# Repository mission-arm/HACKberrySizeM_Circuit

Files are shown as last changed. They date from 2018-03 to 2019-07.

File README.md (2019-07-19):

# HACKberrySizeM_Circuit

This repository contains circuit design of middle sized [HACKberry](https://github.com/mission-arm/HACKberry).

## Licenses

The electrical circuit design of [HACKberry](https://github.com/mission-arm/HACKberry) by [Exiii](info@exiii.jp) is licensed under [Creative Commons License BY-NC-SA 4.0 International](https://creativecommons.org/licenses/by-nc-sa/4.0/).
( Please refer to chapter 3.1 in [Original HACKberry Lincense](https://github.com/mission-arm/HACKberry) for detail. )

And This electrical circuit design of  middle sized HACKberry ) is a derivative of HACKberry and is licensed under [Creative Commons License BY-NC-SA 4.0 International](https://creativecommons.org/licenses/by-nc-sa/4.0/) by MissionARMJapan.

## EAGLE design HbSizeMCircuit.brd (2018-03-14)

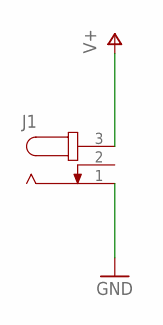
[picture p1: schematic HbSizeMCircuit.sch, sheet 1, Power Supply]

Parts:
J1: JACK-PLUG1; SPC4078

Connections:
GND: J1.1; also elsewhere on the board
V+: J1.3; also elsewhere on the board

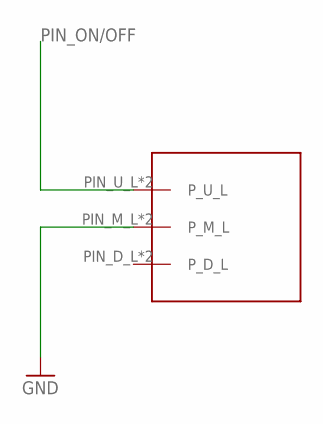
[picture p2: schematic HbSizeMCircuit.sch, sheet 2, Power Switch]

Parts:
U$2: IS-1250_POWERSWITCH

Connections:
GND: U$2.PIN_M_L (P_M_L), U$2.PIN_M_R (P_M_L); also elsewhere on the board
PIN_ON/OFF: U$2.PIN_U_L (P_U_L), U$2.PIN_U_R (P_U_L); also elsewhere on the board

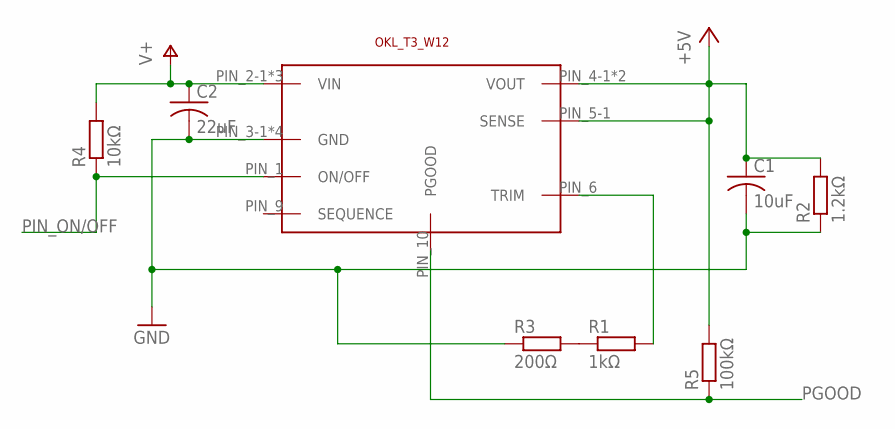
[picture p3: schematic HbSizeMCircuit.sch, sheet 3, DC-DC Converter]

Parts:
C1: 10uF; C1206
C2: 22uF; C1206
R1: 1kΩ; M1206
R2: 1.2kΩ; M1206
R3: 200Ω; M1206
R4: 10kΩ; R1206
R5: 100kΩ; M1206
U$8: OKL_T3_W12

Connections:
+5V: C1.1, R2.2, R5.2, U$8.PIN_4-1 (VOUT), U$8.PIN_4-2 (VOUT), U$8.PIN_5-1 (SENSE); also elsewhere on the board
GND: C1.2, C2.2, R2.1, R3.1, U$8.PIN_3-1 (GND), U$8.PIN_3-2 (GND), U$8.PIN_3-3 (GND), U$8.PIN_7 (GND); also elsewhere on the board
unnamed: R1.2, U$8.PIN_6 (TRIM)
unnamed: R1.1, R3.2
PGOOD: R5.1, U$8.PIN_10 (PGOOD); also elsewhere on the board
PIN_ON/OFF: R4.1, U$8.PIN_1 (ON/OFF); also elsewhere on the board
V+: C2.1, R4.2, U$8.PIN_2-1 (VIN), U$8.PIN_2-2 (VIN), U$8.PIN_2-3 (VIN); also elsewhere on the board

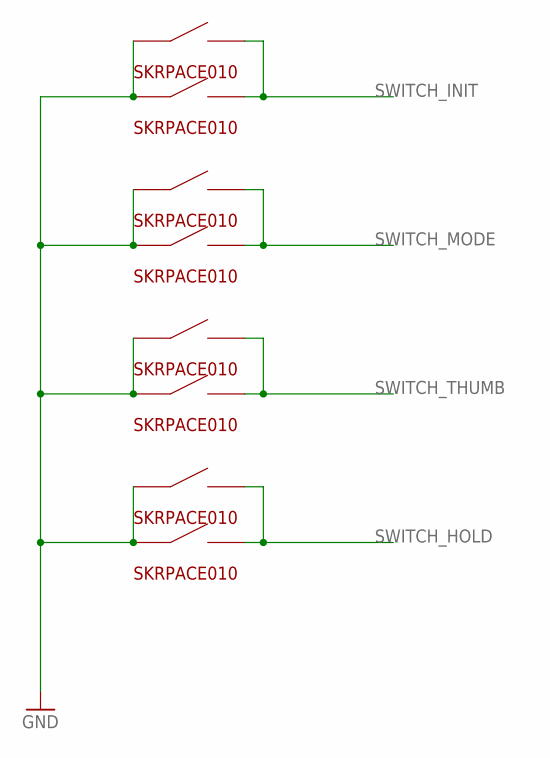
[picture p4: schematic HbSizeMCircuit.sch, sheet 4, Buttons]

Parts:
U$1, U$3, U$4, U$5, U$12, U$13, U$14, U$15: SKRPACE010

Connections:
GND: U$1.PINA_LEFT (A_LEFT), U$1.PINA_RIGHT (A_LEFT), U$3.PINA_LEFT (A_LEFT), U$3.PINA_RIGHT (A_LEFT), U$4.PINA_LEFT (A_LEFT), U$4.PINA_RIGHT (A_LEFT), U$5.PINA_LEFT (A_LEFT), U$5.PINA_RIGHT (A_LEFT), U$12.PINA_LEFT (A_LEFT), U$12.PINA_RIGHT (A_LEFT), U$13.PINA_LEFT (A_LEFT), U$13.PINA_RIGHT (A_LEFT), U$14.PINA_LEFT (A_LEFT), U$14.PINA_RIGHT (A_LEFT), U$15.PINA_LEFT (A_LEFT), U$15.PINA_RIGHT (A_LEFT); also elsewhere on the board
SWITCH_HOLD: U$12.PINB_LEFT (B_LEFT), U$12.PINB_RIGHT (B_LEFT), U$15.PINB_LEFT (B_LEFT), U$15.PINB_RIGHT (B_LEFT); also elsewhere on the board
SWITCH_INIT: U$1.PINB_LEFT (B_LEFT), U$1.PINB_RIGHT (B_LEFT), U$5.PINB_LEFT (B_LEFT), U$5.PINB_RIGHT (B_LEFT); also elsewhere on the board
SWITCH_MODE: U$3.PINB_LEFT (B_LEFT), U$3.PINB_RIGHT (B_LEFT), U$13.PINB_LEFT (B_LEFT), U$13.PINB_RIGHT (B_LEFT); also elsewhere on the board
SWITCH_THUMB: U$4.PINB_LEFT (B_LEFT), U$4.PINB_RIGHT (B_LEFT), U$14.PINB_LEFT (B_LEFT), U$14.PINB_RIGHT (B_LEFT); also elsewhere on the board

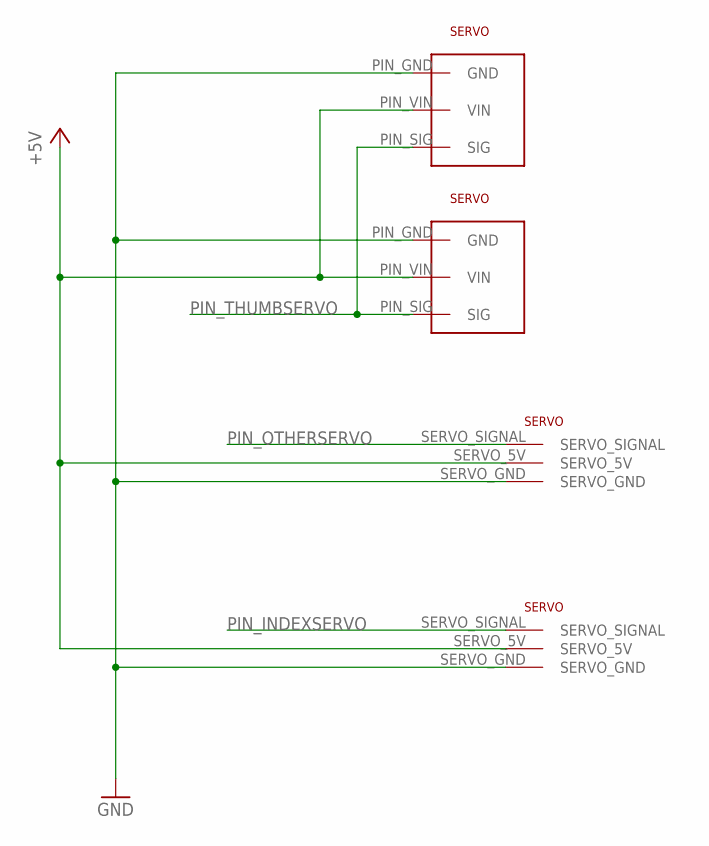
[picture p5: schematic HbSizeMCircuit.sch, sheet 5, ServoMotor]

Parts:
U$7, U$11: NN_SERVO
U$9, U$16: 53398-0371

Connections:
+5V: U$7.SERVO_5V, U$9.PIN_VIN (VIN), U$11.SERVO_5V, U$16.PIN_VIN (VIN); also elsewhere on the board
GND: U$7.SERVO_GND, U$9.PIN_GND (GND), U$11.SERVO_GND, U$16.PIN_GND (GND); also elsewhere on the board
PIN_INDEXSERVO: U$11.SERVO_SIGNAL; also elsewhere on the board
PIN_OTHERSERVO: U$7.SERVO_SIGNAL; also elsewhere on the board
PIN_THUMBSERVO: U$9.PIN_SIG (SIG), U$16.PIN_SIG (SIG); also elsewhere on the board

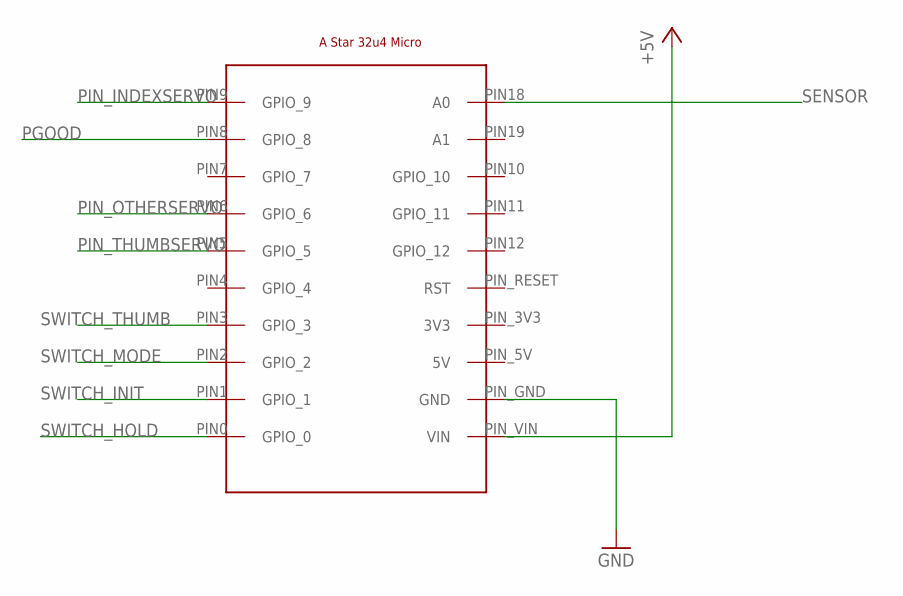
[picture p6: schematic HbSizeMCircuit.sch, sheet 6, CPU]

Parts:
U$6: POLOLU_A_STAR_32U4_MICRO_SMD

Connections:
+5V: U$6.PIN_VIN (VIN); also elsewhere on the board
GND: U$6.PIN_GND (GND); also elsewhere on the board
PGOOD: U$6.PIN8 (GPIO_8); also elsewhere on the board
PIN_INDEXSERVO: U$6.PIN9 (GPIO_9); also elsewhere on the board
PIN_OTHERSERVO: U$6.PIN6 (GPIO_6); also elsewhere on the board
PIN_THUMBSERVO: U$6.PIN5 (GPIO_5); also elsewhere on the board
SENSOR: U$6.PIN18 (A0); also elsewhere on the board
SWITCH_HOLD: U$6.PIN0 (GPIO_0); also elsewhere on the board
SWITCH_INIT: U$6.PIN1 (GPIO_1); also elsewhere on the board
SWITCH_MODE: U$6.PIN2 (GPIO_2); also elsewhere on the board
SWITCH_THUMB: U$6.PIN3 (GPIO_3); also elsewhere on the board

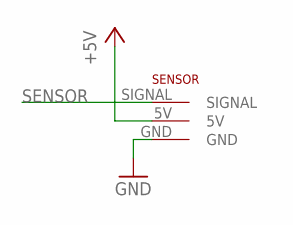
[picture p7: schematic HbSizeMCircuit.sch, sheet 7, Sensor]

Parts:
U$10: NN_SENSOR

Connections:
+5V: U$10.5V; also elsewhere on the board
GND: U$10.GND; also elsewhere on the board
SENSOR: U$10.SIGNAL; also elsewhere on the board

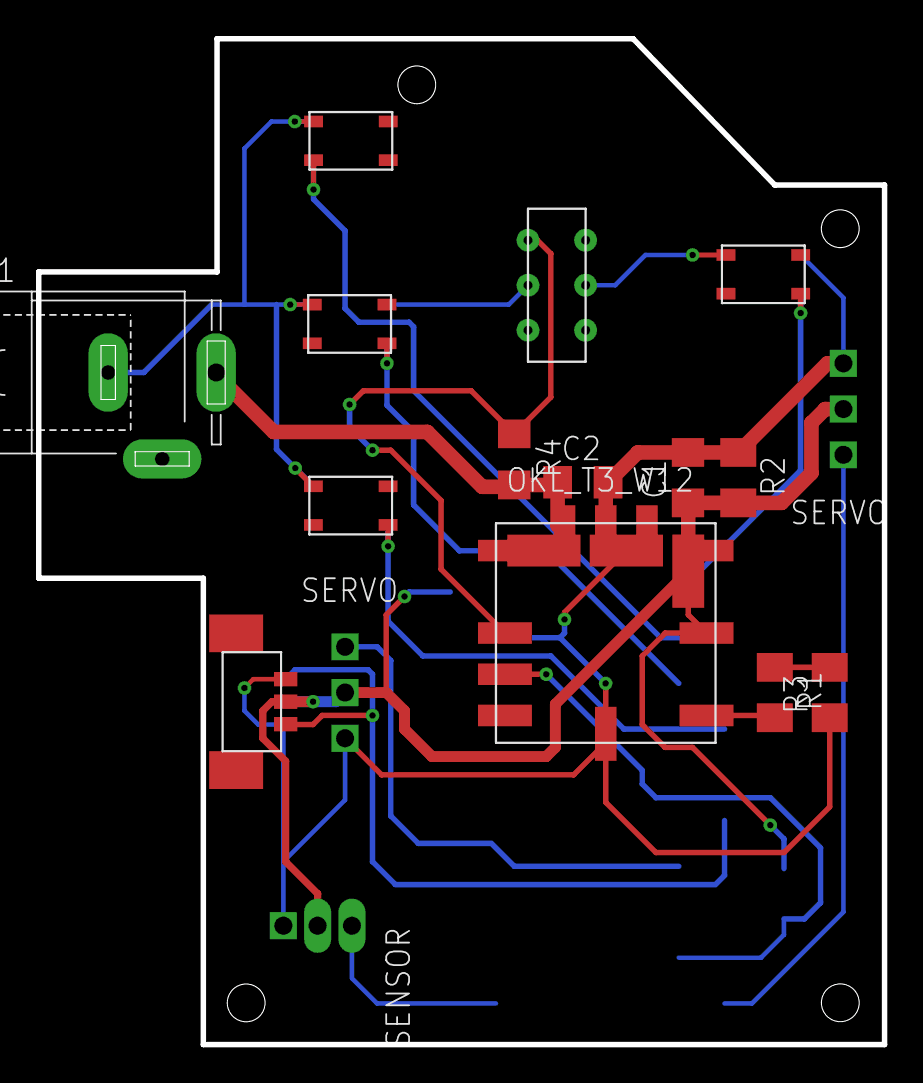
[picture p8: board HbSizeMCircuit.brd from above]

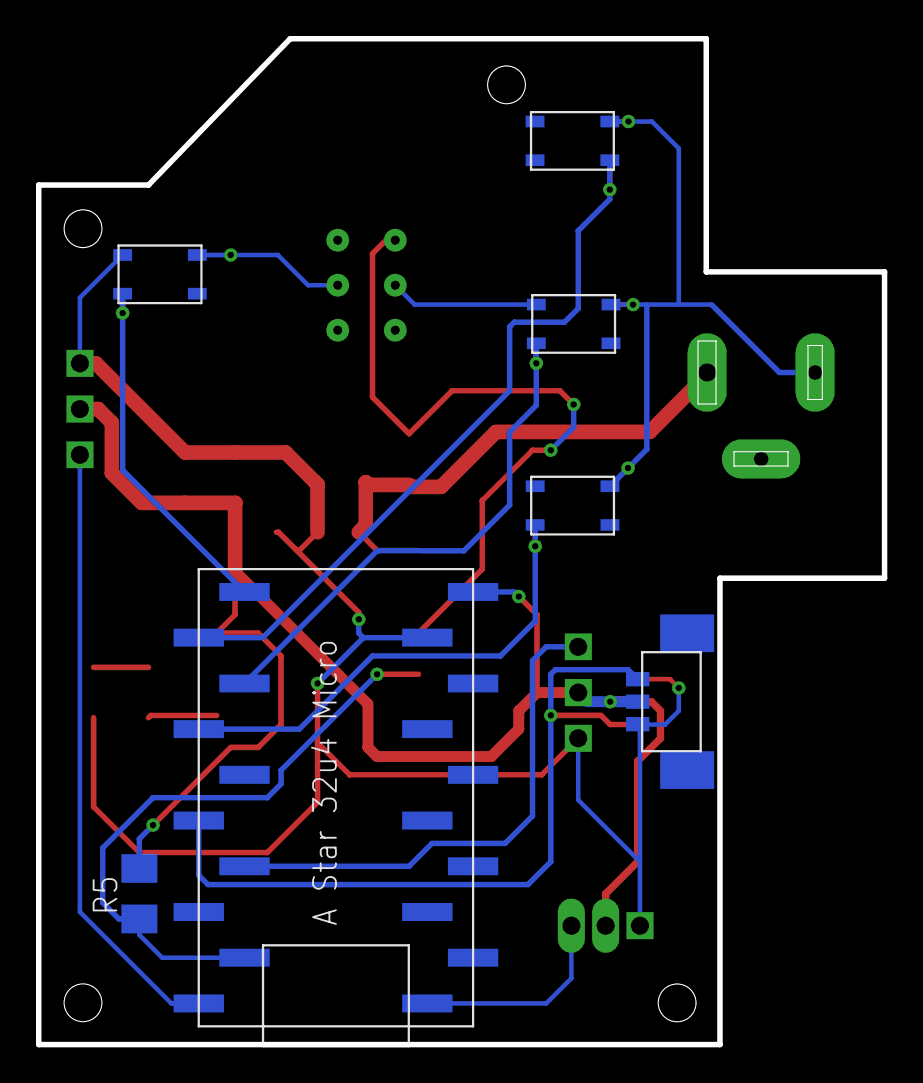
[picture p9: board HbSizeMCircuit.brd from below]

Board: 2 copper layers, 47.0 x 55.9 mm, 24 parts (7 on the bottom side), 15 nets.

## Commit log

2018-03-09 add schematics and board layout
    [HbSizeMCircuit.brd, HbSizeMCircuit.sch]
2018-03-14 DCジャックを変更
    [HbSizeMCircuit.brd, HbSizeMCircuit.sch]
